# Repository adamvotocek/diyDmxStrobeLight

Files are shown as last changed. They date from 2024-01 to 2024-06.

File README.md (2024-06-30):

<!-- TOC -->
# DIY Strobe light with DMX512 functionality

This is a fully functional prototype of a strobe light for stage lighting that can be controlled by the DMX512 protocol. It is based on the ESP32 microcontroller. The plan is to make it into a full product.

Current prototype in action:

prototype

Here is a video of the ESP32 on the mainboard (without the power electronics attached) recieving DMX signal from an Arduino UNO:

DMX recieve video (https://www.youtube.com/watch?v=DUpdl1YqVRM)

<!-- TOC -->
## Table of contents
<!-- TOC start (generated with https://github.com/derlin/bitdowntoc) -->

- [DIY Strobe light with DMX512 functionality](#diy-strobe-light-with-dmx512-functionality)
   * [Table of contents](#table-of-contents)
   * [What is a strobe light?](#what-is-a-strobe-light)
   * [The DMX512 protocol](#the-dmx512-protocol)
      + [What is DMX512?](#what-is-dmx512)
         - [How It Works](#how-it-works)
      + [DMX Sheet](#dmx-sheet)
   * [Electronics used](#electronics-used)
   * [Schematic](#schematic)
   * [Development environment](#development-environment)
      + [IDE and extensions](#ide-and-extensions)
      + [Debugging](#debugging)
   * [Code documentation](#code-documentation)
      + [Files](#files)

<!-- TOC end -->

<!-- TOC -->
## What is a strobe light?

In the field of lighting technology, a strobe light or a stroboscope is a device whose task is to create the impression that the movements of objects are jerky or slowed down. It achieves this with rapid flashes of intense light.

<!-- TOC -->
## The DMX512 protocol

<!-- TOC -->
### What is DMX512?

DMX512, or DMX (Digital Multiplex), is a standard for digital communication networks commonly used to control stage lighting and effects. It works by transmitting up to 512 control channels (hence the name) over a single data link, allowing centralized control of various lighting fixtures, dimmers, and special effects devices.

<!-- TOC -->
#### How It Works

The DMX512 protocol is based on the RS485 standard which uses differential signaling with voltage levels typically ranging from -5 V to +5 V. This allows for better immunity to interference and is thus suitable for longer distance communication. Communication is multipoint, enabling multiple devices to be connected to the same bus. 

Each channel carries an 8-bit value (0-255), which corresponds to different parameters of the lighting fixture (e.g., intensity, color, position).

A single DMX network, or "universe," consists of 512 channels. Multiple universes can be used for larger setups.

Devices are connected in a daisy-chain configuration using 5-pin XLR cables (although 3-pin cables are also common).

DMX512 has become the standard for stage lighting, but it is also used in architectural lighting or special effects.

<!-- TOC -->
### DMX Sheet

This is how the LED reacts to different channel values.

| Channel | Value | Function |
| --- | --- | --- |
| 1 | 000 - 255 | Intensity 0 - 100% |
| 2 | 000 - 255 | Strobe effect speed 1 - 25 Hz |
| | 000 - 004 | Blackout |
| 3 | 005 - 250 | Strobe duty cycle 0 - 100% |
| | 251 - 255 | Blinder (Light on) |

<!-- TOC -->
## Electronics used

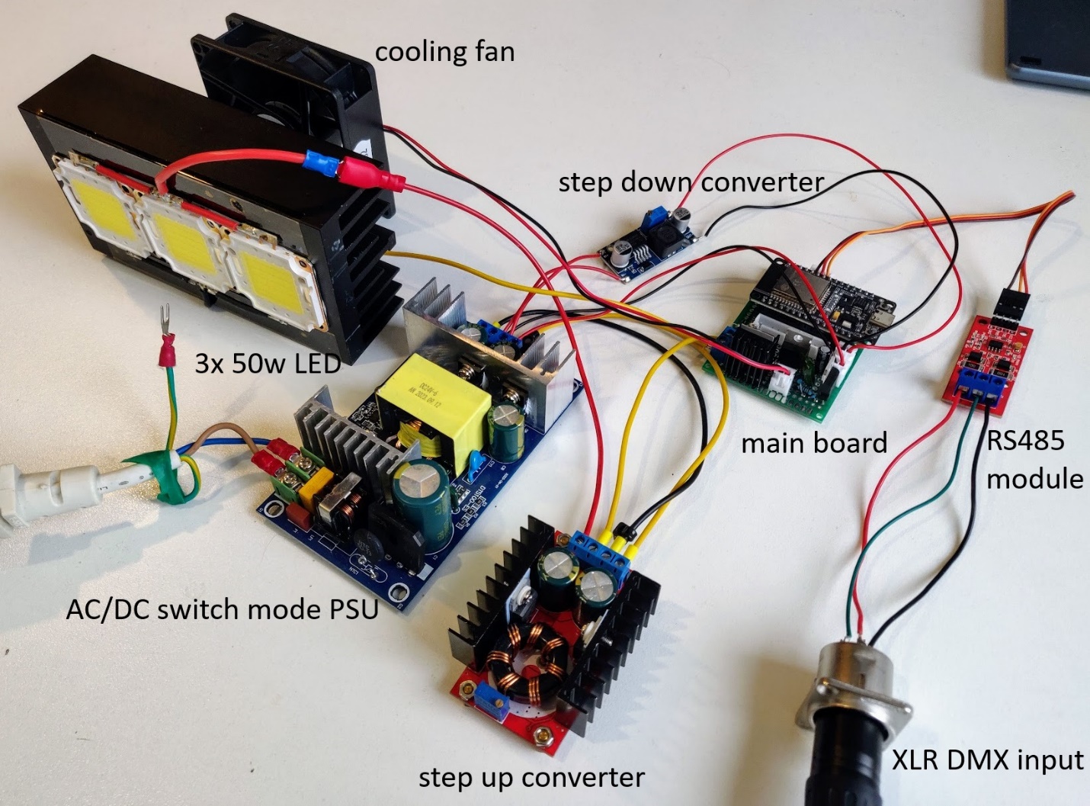
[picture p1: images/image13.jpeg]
electronics skeleton


The brain of the whole project is a dual-core ESP32 development board, which is seated into a custom made mainboard.

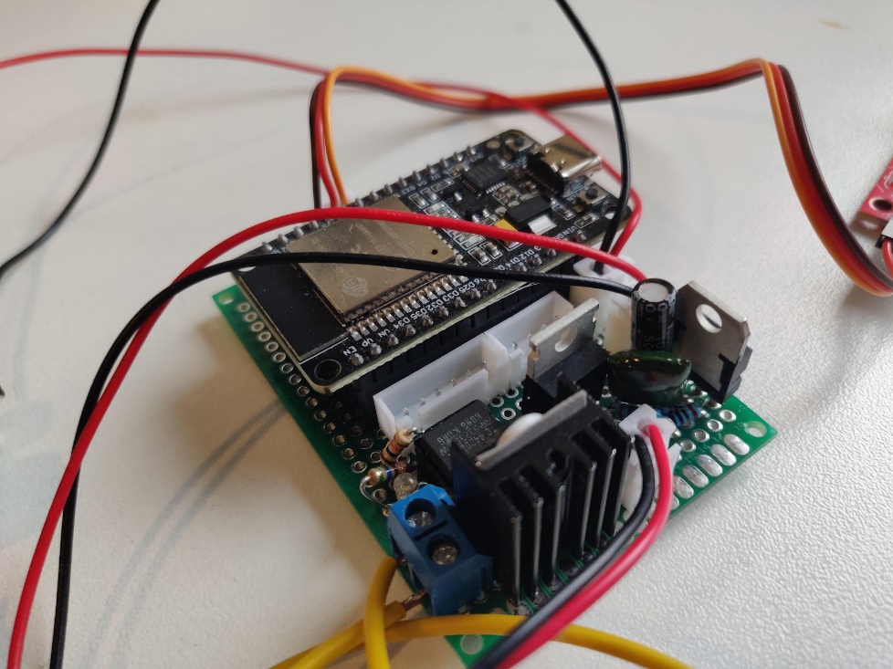
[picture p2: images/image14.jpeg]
mainboard1

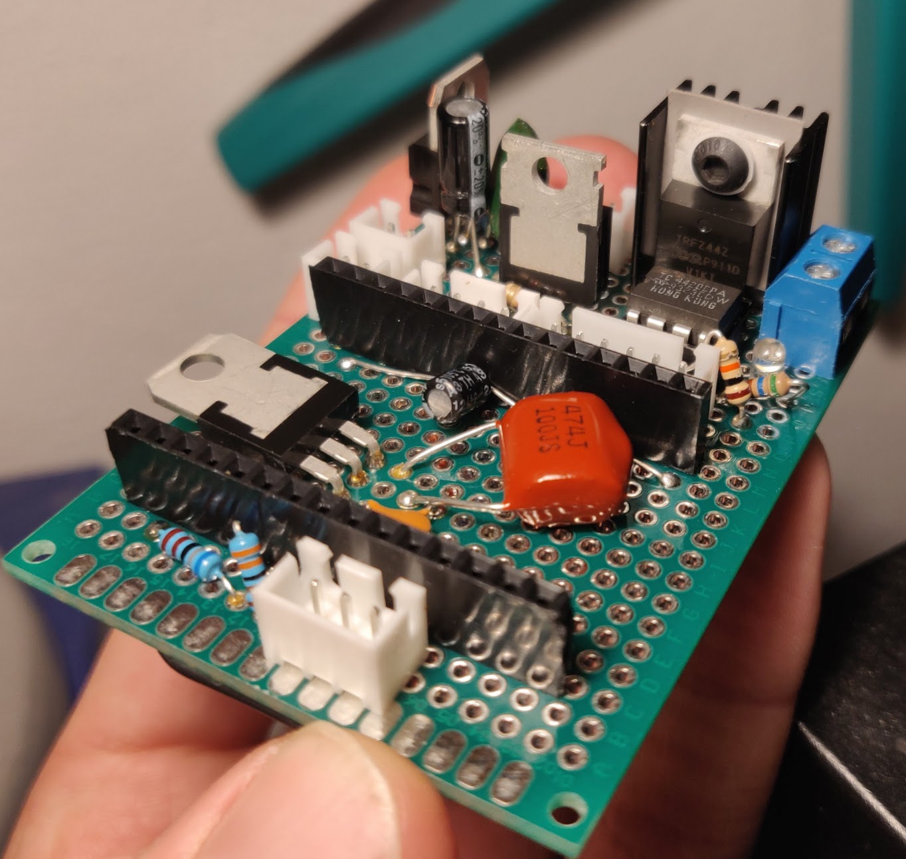
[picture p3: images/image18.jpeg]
mainboard2

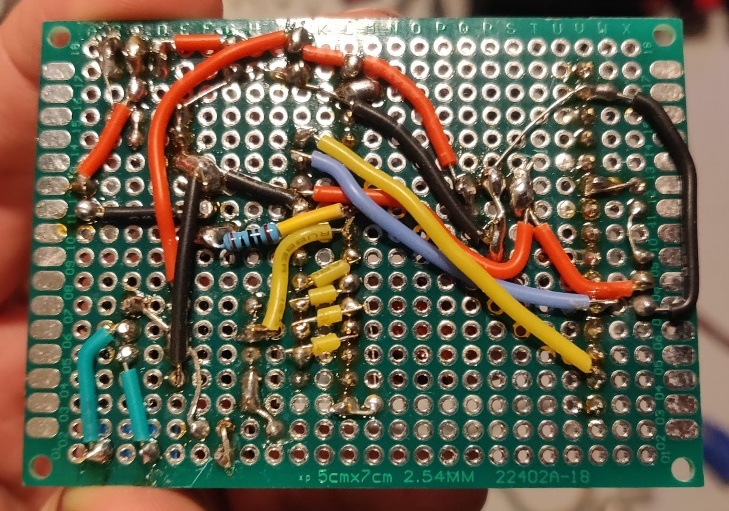
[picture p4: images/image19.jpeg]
mainboard3

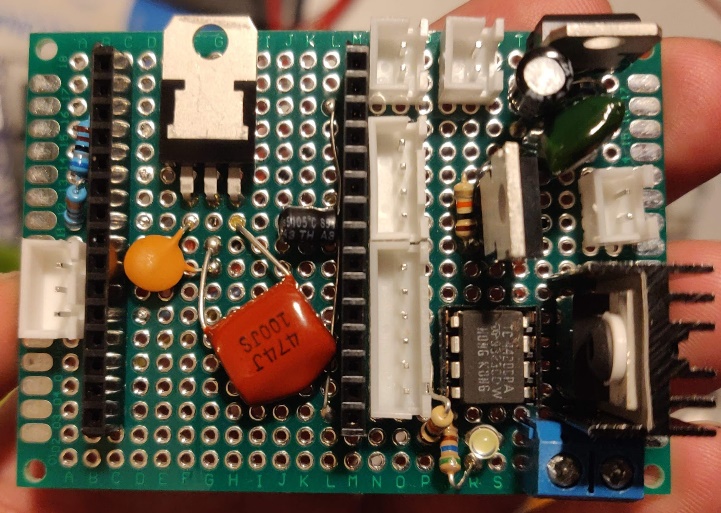
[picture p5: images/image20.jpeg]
mainboard4


The microcontroller itself cannot receive the DMX signal, which is based on the RS485. The conversion of the RS485 signal to serial, which the ESP can process on one of its UARTs, is provided by a module built with the MAX485 chip. 

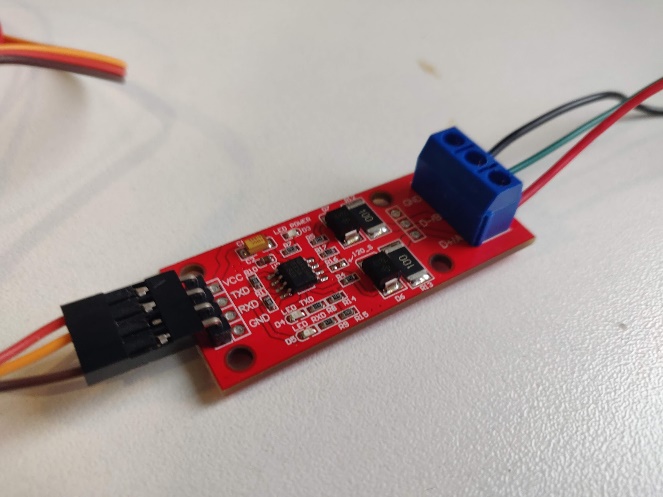
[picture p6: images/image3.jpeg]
RS485 module


The ESP has a TC4420 MOSFET driver connected to pin 25. It can very quickly switch the MOSFET IRFZ44N, through which three COB LEDs are connected, with a combined power of 150W. 

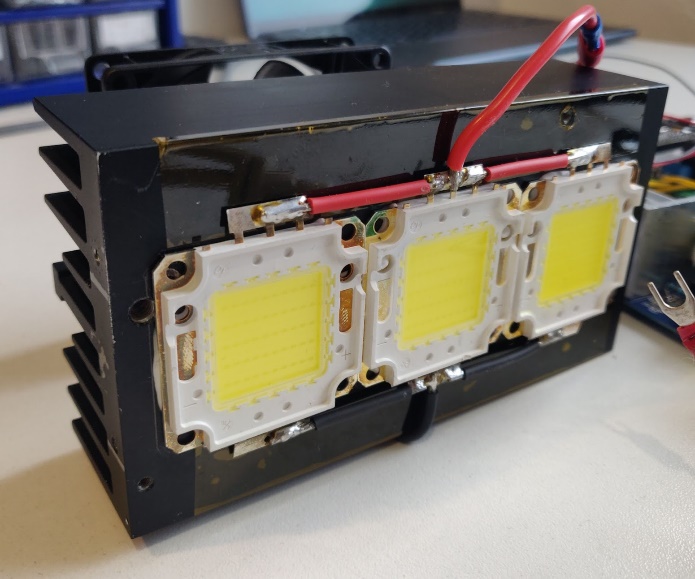
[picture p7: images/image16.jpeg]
powerLeds


An iteresting obstacle in this project is the number of voltage levels present in it. The LEDs run at 32V, the fan at 24V, the MOSFET driver should have a voltage greater than 5V, RS485 needs 5V and its logic is five volts, and the ESP32 can be powered with a higher voltage than 3.3V, but its logic will remain at 3.3V. I solved this with different converters and voltage regulators. It is a bit messy, but it's what I already had.

For the power LEDs I use a boost converter module that can handle up to 10A. The module increases the voltage from 24V to 32V. 

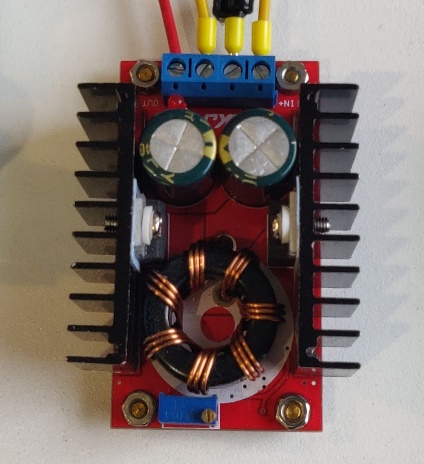
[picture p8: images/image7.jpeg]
boost


To get the 9V for the MOSFET and ESP. For this I used a buck converter.

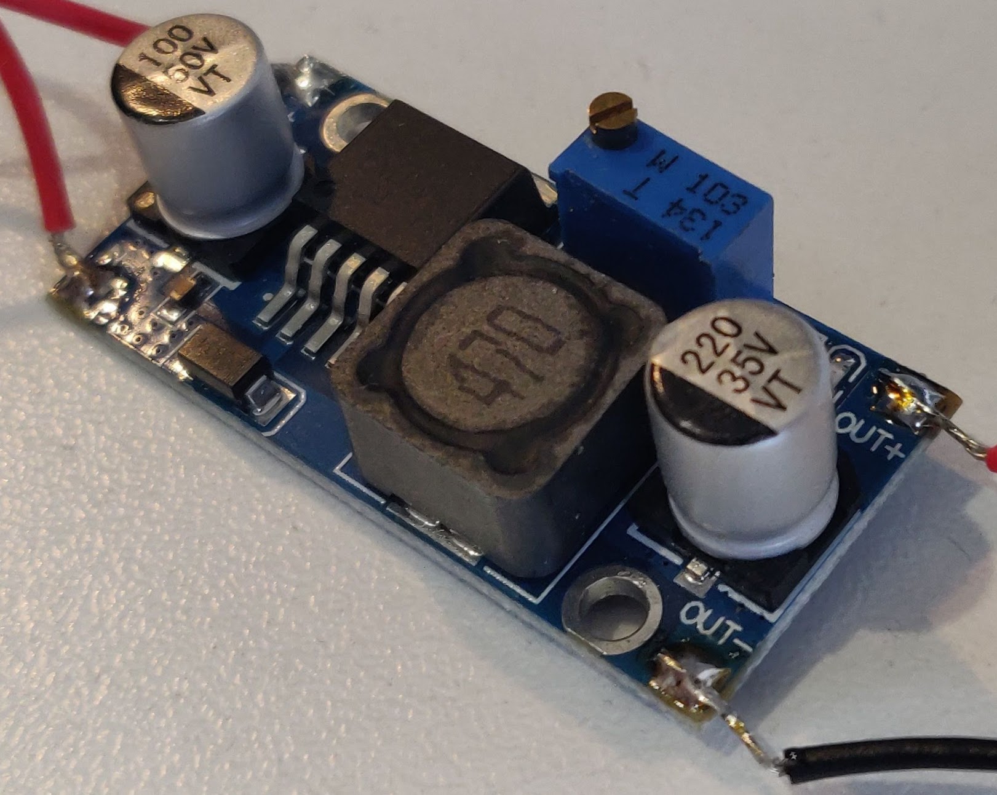
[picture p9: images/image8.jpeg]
buck


To obtain 5V for the RS485 module, I used a linear voltage regulator called L7805 with two capacitors for voltage stability. 

In order to be able to read data from this five-volt module using ESP, I had to add a voltage divider to the data pin, which turned the 5V signal into a 3.3V signal.

I was unable to find a suitable 24V voltage source from which to power the entire device. I had access to a good 28v supply so I used that. But it means that an additional voltage regulator is needed, because the fan for cooling the LED runs on 24V. I didn't have an L7824, so I used an LM317, along with two resistors for voltage adjustment and two capacitors for stabilization. However, I didn't want to complicate the schematic even more, because 24V sources are standard and the fact that I have a 28V source is rather an exception, so I didn't include that there.

<!-- TOC -->
## Schematic

[Fritzing schematic here](https://github.com/adamvotocek/diyDmxStrobeLight/tree/main/schematic)

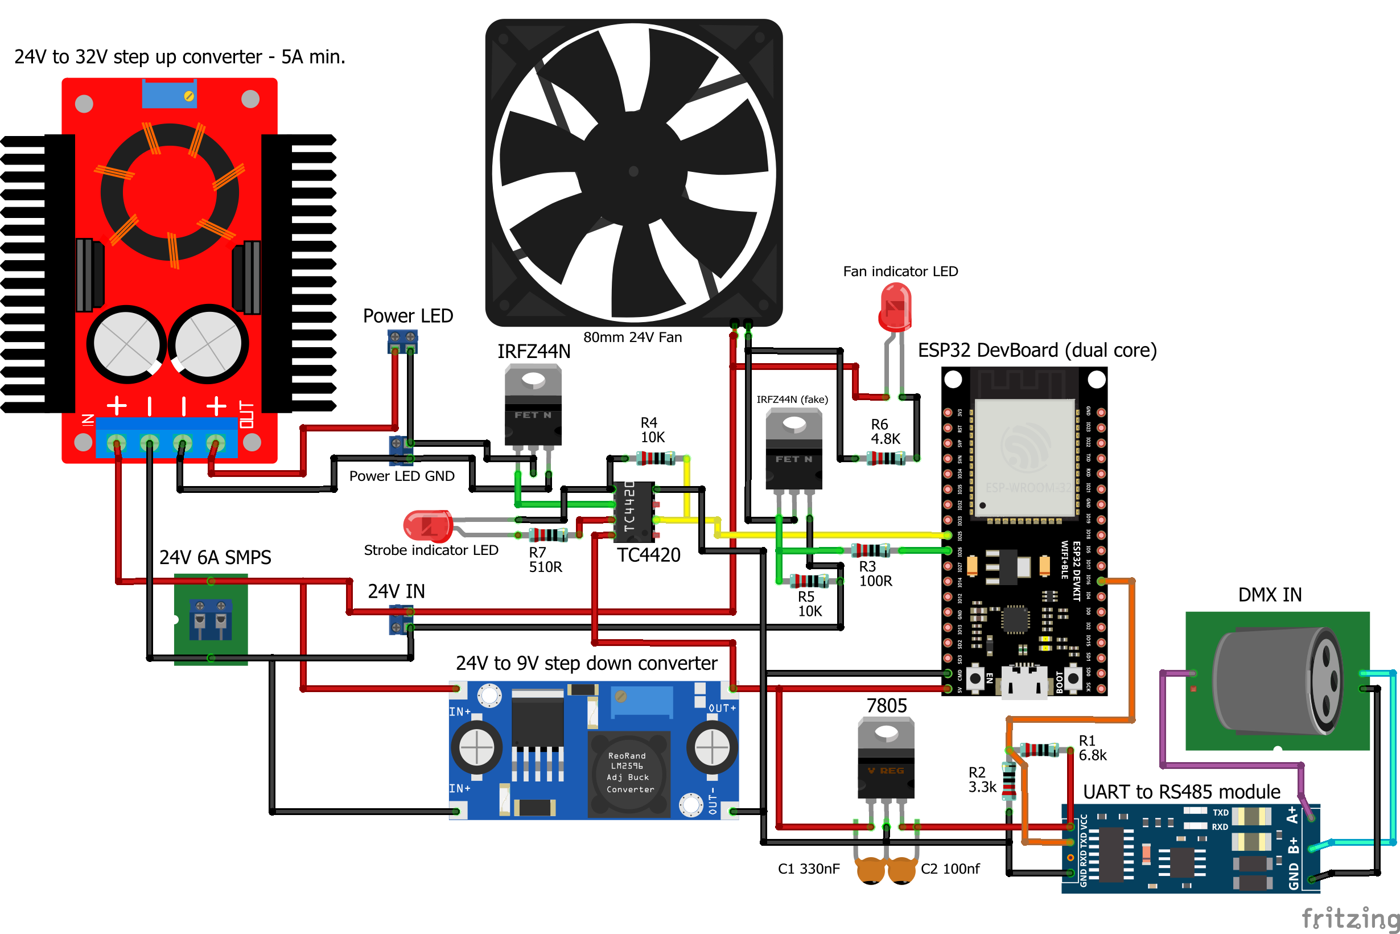
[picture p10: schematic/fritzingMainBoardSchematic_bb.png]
schematic


<!-- TOC -->
## Development environment

<!-- TOC -->
### IDE and extensions

This project is made in [Visual Studio Code](https://code.visualstudio.com/) with the [Platformio](https://platformio.org/) extension which allows easy embedded platform development. 

<!-- TOC -->
### Debugging

I used the [ESP-Prog debugger](https://docs.platformio.org/en/stable/plus/debug-tools/esp-prog.html) for hardware JTAG debugging. I also connected the ESP32s RX0, TX0 and EN with it so that I could use the serial monitor. The Platformio debug configuration is reflected in the platformio.ini file.

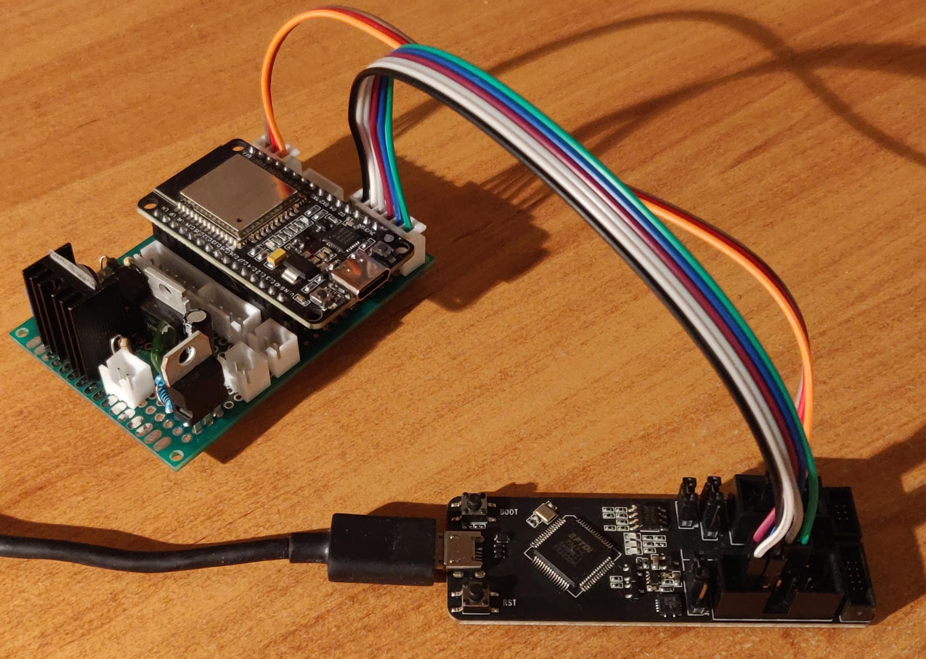
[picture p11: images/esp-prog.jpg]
esp-prog


<!-- TOC -->
## Code documentation
   
This project's code relies on the well known Arduino framework and on the [Espressif's port of FreeRTOS for the ESP32](https://docs.espressif.com/projects/esp-idf/en/stable/esp32/api-reference/system/freertos.html). FreeRTOS providies multitasking capabilities by running a scheduler that switches between created tasks. It is useful because it allows to efficiently do multiple different things concurrently on the ESP32's dual-core processor. 

[Learn how the FreeRTOS scheduler switches between tasks here](https://www.freertos.org/implementation/a00008.html)

The FreeRTOS port is compiled in Espressif's ESP-IDF framework, which focuses on the C language. However, I wanted to use an object oriented approach for easier future additions to the project, so I tried to write as much as I could in C++ (this is also one of the reasons for choosing the Arduino framework). Because the FreeRTOS functions are made for C programming, I am using a C++ wrapper library called `WrapperFreeRTOS`. It made it a little easier to work with, but some workarounds were still needed. 

In this case, the program is split into 3 tasks:

`LogTask` - Handles logging to the microcontrollers UART, which can be recieved in the serial monitor of a connected computer. If other tasks want to log something, they send an entry to this task via a queue.

`DmxTask` - Uses the esp_dmx library to recieve DMX512 packets from the RS485 to serial module and sends them to the `LedControlTask` via a queue. 

`LedControlTask` - Reads recieved DMX data from a queue and controls the LED accordingly. It utilizes software timers to create a strobe effect and uses the ledCxxx functions to dim the LED via PWM (pulse width modulation).

<!-- TOC -->
### Files
`main.cpp` - The core of the program.

`deviceConfig.hpp` - Configuration file for things like pin numbers or LED parameters.

`logTask.hpp` - Header file for the logging task.

`logTask.cpp` - Implementation of the logging task.

`dmxTask.hpp` - Header file for the DMX512 recieve task.

`dmxTask.cpp` - Implementation of the DMX512 recieve task.

`ledControlTask.hpp` - Header file for the task for led control.

`ledControlTask.cpp` - Implementation of the task for led control.

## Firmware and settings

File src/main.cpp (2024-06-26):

#include <Arduino.h>
#include <esp_log.h>

// Configuration of things like pin numbers and other device specific settings
#include "deviceConfig.hpp"

// Import all the different tasks.
// Because of cross-dependencies, the implementations already construct a global instance of each task.
#include "dmxTask.hpp"
#include "ledControlTask.hpp"
#include "logTask.hpp"

// Tag for logging, this should be in every file that logs anything
static const char *TAG = "main.cpp";

void setup() {
    // Turn on the fan attached to the mosfet
    pinMode(DEVICECONF_FAN_PIN, OUTPUT);
    digitalWrite(DEVICECONF_FAN_PIN, HIGH);

    // Setup tasks
    logTask.setup();
    dmxTask.setup();
    ledControlTask.setup();

    // Start tasks
    logTask.start();
    dmxTask.start();
    ledControlTask.start();

    logTask.queueLog(TAG, "Setup complete", LogLevel::DEBUG);  // Log that the setup is complete
    vTaskDelete(NULL);                                         // Delete "setup and loop" task
}

void loop() {}  // This should never get executed as this task is deleted in setup

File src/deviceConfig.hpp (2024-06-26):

#pragma once

// PINS
//  Dmx module
// in my case I can only use TX2, because TX0 is connected to the esp-prog and used for serial communication
#define DEVICECONF_DMX_TX_PIN 17 // 1=TX0, 17=TX2
#define DEVICECONF_DMX_RX_PIN 16 // 3=RX0, 16=RX2
#define DEVICECONF_DMX_RTS_PIN 4
// LED mosfet driver
#define DEVICECONF_STROBE_LED_PIN 25
// Fan mosfet
#define DEVICECONF_FAN_PIN 26
// Display // TODO: Add display and menu control
#define DEVICECONF_DISPLAY_SDA_PIN 21
#define DEVICECONF_DISPLAY_SCL_PIN 22
// Buttons // TODO: Add buttons to control the device
#define DEVICECONF_MODE_BUTTON_PIN 34
#define DEVICECONF_PLUS_BUTTON_PIN 35
#define DEVICECONF_MINUS_BUTTON_PIN 32
#define DEVICECONF_ENTER_BUTTON_PIN 33

// PWM Led control
#define DEVICECONF_PWM_CHANNEL 0
#define DEVICECONF_PWM_FREQUENCY 5000 // Hz

// DMX 
#define DEVICECONF_DMX_PORT DMX_NUM_2

// Effects
// Strobe
#define DEVICECONF_STROBE_PERIOD_MIN 30 // ms
#define DEVICECONF_STROBE_PERIOD_MAX 999 // ms

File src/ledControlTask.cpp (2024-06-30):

#include "ledControlTask.hpp"

#include <Arduino.h>
#include <esp_log.h>

#include "deviceConfig.hpp"
#include "dmxTask.hpp"
#include "logTask.hpp"

// Global instance of the LedControlTask
LedControlTask ledControlTask(2048, 1, APP_CPU_NUM);

// Log tag for this file
static const char *TAG = "LedConTask";

// Static variables
TimerHandle_t LedControlTask::m_ledOnTimerHandle = NULL;
TimerHandle_t LedControlTask::m_ledOffTimerHandle = NULL;
TimerHandle_t LedControlTask::m_syncTimerHandle = NULL;
DmxMode<3> LedControlTask::recievedDmx;
strobeParameters LedControlTask::strobe;

LedControlTask::LedControlTask(uint32_t stackSize, uint8_t priority, uint8_t coreId)
    : Task("LedControlTask", stackSize, priority) {
    setCore(coreId);
    m_ledOnTimerHandle = NULL;
    m_ledOffTimerHandle = NULL;
    m_syncTimerHandle = NULL;
}

void LedControlTask::createTimers() {
    // Create timers
    m_ledOnTimerHandle = xTimerCreate("LedONTimer", pdMS_TO_TICKS(9999), pdFALSE, NULL, ledOnTimerCallback);
    m_ledOffTimerHandle =
        xTimerCreate("LedOFFTimer", pdMS_TO_TICKS(9999), pdFALSE, NULL, ledOffTimerCallback);
    m_syncTimerHandle = xTimerCreate("SyncTimer", pdMS_TO_TICKS(9999), pdFALSE, NULL, syncTimerCallback);

    if (m_ledOnTimerHandle == NULL || m_ledOffTimerHandle == NULL || m_syncTimerHandle == NULL) {
        if (m_ledOnTimerHandle == NULL) {
            ESP_LOGE(TAG, "Error creating the led ON timer");
        }
        if (m_ledOffTimerHandle == NULL) {
            ESP_LOGE(TAG, "Error creating the led OFF timer");
        }
        if (m_syncTimerHandle == NULL) {
            ESP_LOGE(TAG, "Error creating the one shot sync timer");
        }
        restartCPU(TAG);
    }
}

void LedControlTask::setup()
{
    // LED PWM configuration
    ledcSetup(DEVICECONF_PWM_CHANNEL, DEVICECONF_PWM_FREQUENCY, 8);
    ledcAttachPin(DEVICECONF_STROBE_LED_PIN, DEVICECONF_PWM_CHANNEL);
    // Default state of the LED
    ledcWrite(DEVICECONF_PWM_CHANNEL, 0);
    strobe.isLedOn = false;
    
    createTimers();
}

void LedControlTask::run(void *data)
{
    char message[70];
    DmxMode<3> lastEffectParameters;
    int strobePeriod;
    if (xQueueReceive(dmxTask.getQueueHandle(), &recievedDmx, portMAX_DELAY) == pdTRUE) {
        strobePeriod = getStrobePeriod();
        strobe.dutyCycle = recievedDmx.data[0];
        strobe.lightOnTime = map(recievedDmx.data[2], STROBE_DURATION_MIN, STROBE_DURATION_MAX, 1, strobePeriod - 1);
        strobe.lightOffTime = strobePeriod - strobe.lightOnTime;
        ledOnTimerCallback(NULL);
        lastEffectParameters = recievedDmx;
    }
    while (true) {
        if (xQueueReceive(dmxTask.getQueueHandle(), &recievedDmx, portMAX_DELAY) == pdTRUE) {
            strobePeriod = getStrobePeriod();
            strobe.dutyCycle = recievedDmx.data[0];
            if (recievedDmx.data[2] > STROBE_BLACKOUT_MAX && recievedDmx.data[2] < STROBE_LIGHT_FULL_ON_MIN) {
                strobe.lightOnTime =
                    map(recievedDmx.data[2], STROBE_DURATION_MIN, STROBE_DURATION_MAX, 1, strobePeriod - 1);
                strobe.lightOffTime = strobePeriod - strobe.lightOnTime;
            }
            if (recievedDmx.data[1] != lastEffectParameters.data[1]) {
                refreshSyncTimer();
            }
            if (recievedDmx.data[0] != lastEffectParameters.data[0] && strobe.isLedOn) {
                setLightPwm();
            }
            lastEffectParameters = recievedDmx;
        } else {
            logTask.queueLog(TAG, "Error receiving ledEffectParameters from queue", LogLevel::ERROR);
        }
    }
}

void LedControlTask::ledOnTimerCallback(TimerHandle_t xTimer)
{
    setLightPwm();
    strobe.isLedOn = true;
    strobe.lastSwitch = millis();
    refreshLedOffTimer();
}

void LedControlTask::ledOffTimerCallback(TimerHandle_t xTimer)
{
    ledcWrite(DEVICECONF_PWM_CHANNEL, 0);
    strobe.isLedOn = false;
    strobe.lastSwitch = millis();
    refreshLedOnTimer();
}

void LedControlTask::syncTimerCallback(TimerHandle_t xTimer)
{
    char message[100];
    logTask.queueLog(TAG, "SYNC timer expired", LogLevel::VERBOSE);
    switchOnOff();
    if (strobe.isLedOn) {
        if (xTimerChangePeriod(m_ledOffTimerHandle, pdMS_TO_TICKS(strobe.lightOnTime), portMAX_DELAY) != pdPASS) {
            sniprintf(message, sizeof(message), "Error changing ledOFF timer period, tried %d",
                      strobe.lightOnTime);
            logTask.queueLog(TAG, message, LogLevel::ERROR);
        } else {
            snprintf(message, sizeof(message), "Changed ledOFF timer period to %d", strobe.lightOnTime);
            logTask.queueLog(TAG, message, LogLevel::VERBOSE);
        }
    } else {
        if (xTimerChangePeriod(m_ledOnTimerHandle, pdMS_TO_TICKS(strobe.lightOffTime), portMAX_DELAY) != pdPASS) {
            sniprintf(message, sizeof(message), "Error changing ledOFF timer period, tried %d",
                      strobe.lightOffTime);
            logTask.queueLog(TAG, message, LogLevel::ERROR);
        } else {
            snprintf(message, sizeof(message), "Changed the led ON timer period to %d", strobe.lightOffTime);
            logTask.queueLog(TAG, message, LogLevel::VERBOSE);
        }
    }
}

int LedControlTask::getStrobePeriod()
{
    return map(recievedDmx.data[1], 0, 255, DEVICECONF_STROBE_PERIOD_MAX, DEVICECONF_STROBE_PERIOD_MIN);
}

void LedControlTask::setLightPwm()
{
    if (recievedDmx.data[2] >= STROBE_BLACKOUT_MIN && recievedDmx.data[2] <= STROBE_BLACKOUT_MAX) {
        ledcWrite(DEVICECONF_PWM_CHANNEL, 0);
    } else {
        ledcWrite(DEVICECONF_PWM_CHANNEL, recievedDmx.data[0]);
    }
}

void LedControlTask::switchOnOff()
{
    if (strobe.isLedOn) {
        ledcWrite(DEVICECONF_PWM_CHANNEL, 0);
        strobe.isLedOn = false;
        strobe.lastSwitch = millis();
        logTask.queueLog(TAG, "LED OFF", LogLevel::VERBOSE);
    } else {
        setLightPwm();
        strobe.isLedOn = true;
        strobe.lastSwitch = millis();
        logTask.queueLog(TAG, "LED ON", LogLevel::VERBOSE);
    }
}

void LedControlTask::refreshLedOnTimer()
{
    xTimerChangePeriod(m_ledOnTimerHandle, pdMS_TO_TICKS(strobe.lightOffTime), portMAX_DELAY);
    if (m_ledOnTimerHandle == NULL) {
        logTask.queueLog(TAG, "Error refreshing the led ON timer", LogLevel::ERROR);
    }
}

void LedControlTask::refreshLedOffTimer()
{
    xTimerChangePeriod(m_ledOffTimerHandle, pdMS_TO_TICKS(strobe.lightOnTime), portMAX_DELAY);
    if (m_ledOffTimerHandle == NULL) {
        logTask.queueLog(TAG, "Error refreshing the led OFF timer", LogLevel::ERROR);
    }
}
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

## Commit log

2023-12-27 led pwm
2024-01-02 Refactor LED PWM and DMX configuration
2024-01-02 fixed obvious problems of last commit
    [main.cpp]
2024-01-03 update the ledControlTask to make the strobe effect and make it instatly react to changes
2024-01-07 Add main board schematic
    [fritzingMainBoardSchematic.fzz]
2024-01-07 update schematic
    [fritzingMainBoardSchematic.fzz]
2024-06-22 moved some values into deviceConfig.h, other refactoring
2024-06-23 encapsulated a part of the serialPrintTask. switching to a cpp wrapper next
2024-06-25 added the pinout of the specific ESP32 dev board that I am using
2024-06-26 changed log level to debug, verbose logging is currently so frequent that it delays the led
2024-06-26 rewrote the led control task into an object and moved it into seperate files
